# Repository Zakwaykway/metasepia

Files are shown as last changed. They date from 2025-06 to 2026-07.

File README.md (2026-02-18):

# Metasepia

An ergogenerated hummingbird-esque keyboard, inspired by jcmkk3's rufous, modified to my taste.

v2 is in development.

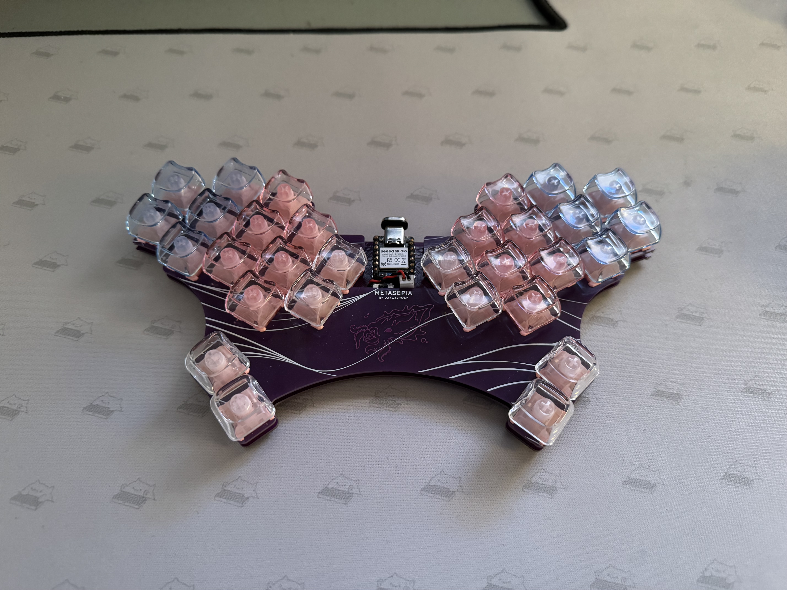
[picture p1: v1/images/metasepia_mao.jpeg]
mao


## Notable changes
  - Aggressive stagger (especially on index),
  - Wider thumbs,
  - Wireless compatibility,
  - Hotswappable,
  - And a breakable bottom pinky key (bound to top pinky's assignment in v1).

The pcb in v1/production is tested; fully functional with both xiao rp2040 & xiao nrf52840.

ZMK module (wired + wireless firmware) can be found at [zmk-keyboard-metasepia](https://github.com/zakwaykway/zmk-keyboard-metasepia).

front | back
-|-
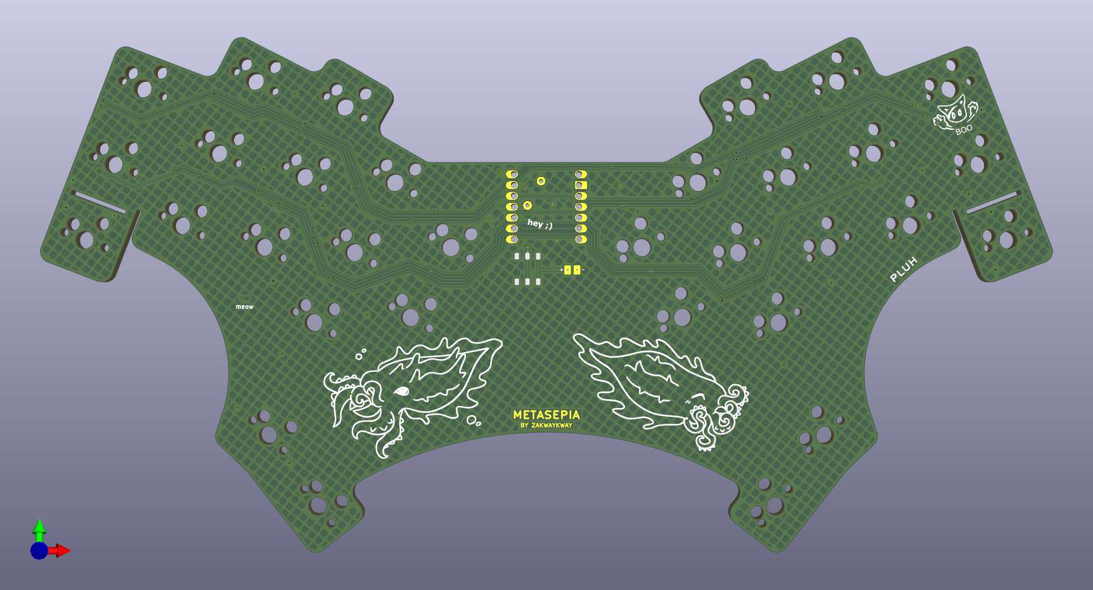
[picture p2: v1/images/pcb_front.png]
front
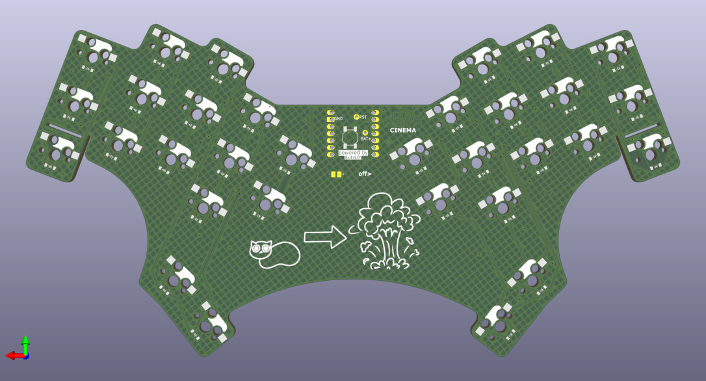
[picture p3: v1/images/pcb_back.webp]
back
 | 

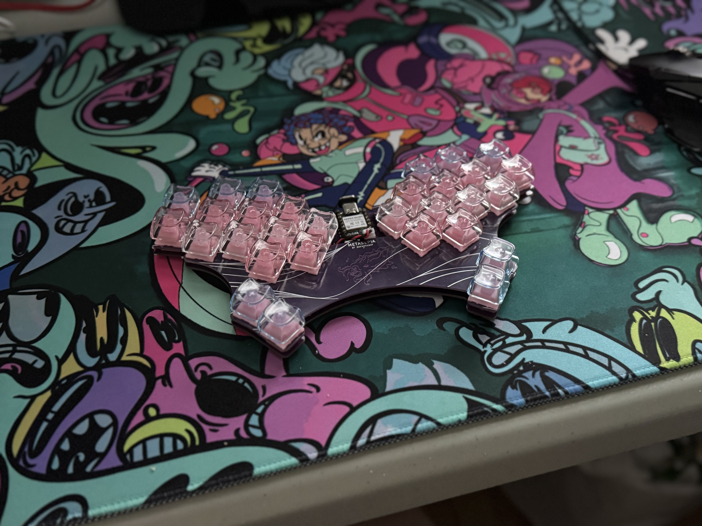
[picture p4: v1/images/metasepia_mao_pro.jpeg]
pro


## Assembly
### Components
- BOM.md
- If wireless isn't needed: BAT+ pogo, power slider, and battery aren't needed. Reset pogo & button are also optional, as there are other ways to trigger a reset.

### Build guide
0. **Optional:** remove bottom pinky key by cutting its traces, scoring the pcb at the tabs, and snapping off.
1. On **back** face: Tin **ONE** pad of each component.
2. Insert all hotswap sockets, and reflow tinned pads.
3. For diodes, I place and reflow one at a time, because they are a lot smaller & tend to jump around. 
4. Then, solder diodes' and sockets' 2nd (untinned) pads.
5. Solder reset button. 
6. On **front** face: solder slider switch, then MCU sockets.
7. Solder pogos. If male pins aren't soldered to the mcu yet, do that BEFORE adding pogos—doing it after is very tedious and annoying.
8. If careful, it IS POSSIBLE to solder a female JST-PH 2-pin connector. Its legs should be pointed **away** from the MCU (south). It is important that it be placed as close to the MCU as possible, or the plate won't fit over it.
9. **Enjoy your new keyboard!** Send me pics, suggestions, or comments @zakwaykway on discord \:))

## Thanks:
Making metasepia was an intensive learning experience, and a huge pride. 
Thanks to mrzealot for ergogen, ceoloide for their fork of ergogen, flatfootfox for their guide to ergogen; 
To the fingerpunch and 40% keyboard servers for questions and inspiration; 
To jcmkk3 for rufous' ergogen config; 
To ZMK for being an amazing keyboard firmware; 
To my friends, for making the art that's on the board;
And to all who have open-sourced their work, whether pcbs, footprints, or firmware--this wouldn't be possible without you.

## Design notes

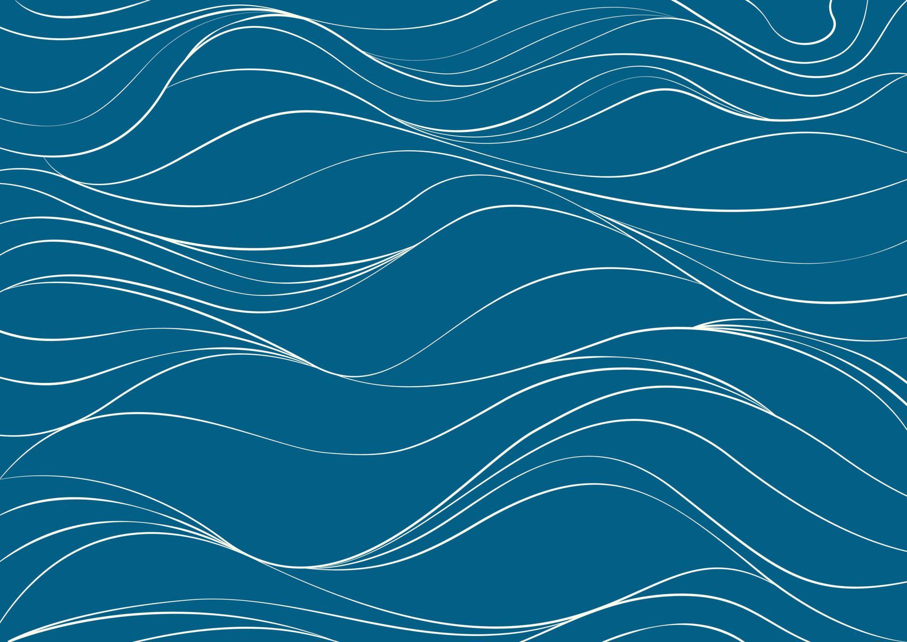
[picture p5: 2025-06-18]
art/abstract-texture-background-template-of-water-sea-aqua-ocean-river-or-mountain-doodle-wavy-line-curve-linear-wave-free-form-repeat-pattern-stripe-ripple-flat-illustration-design-vector-1491954462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

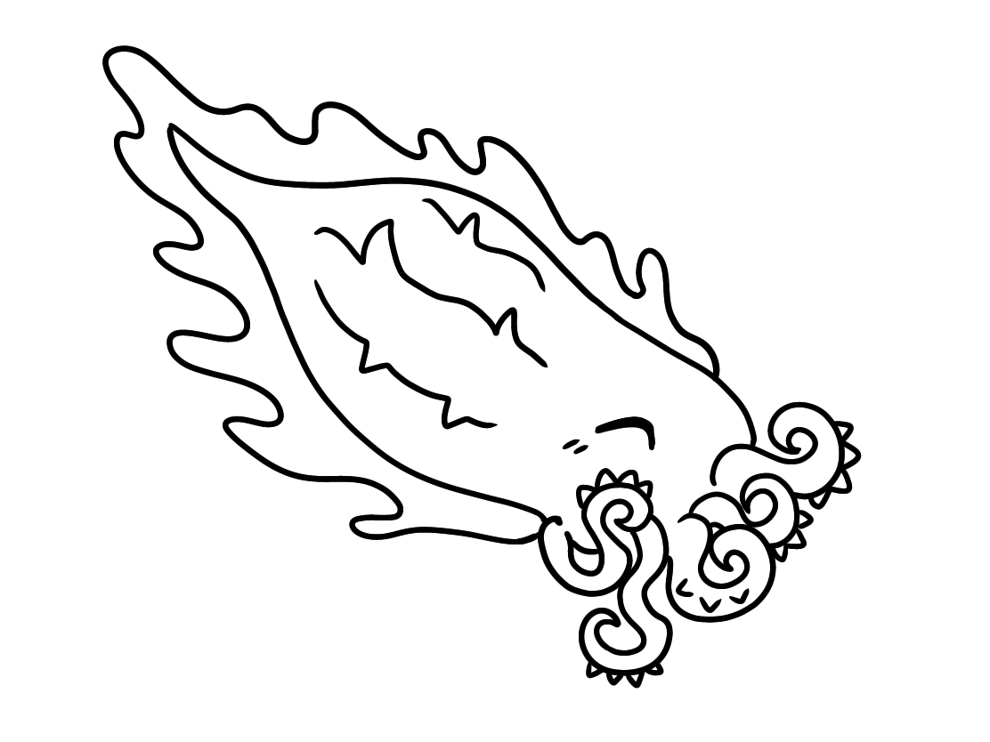
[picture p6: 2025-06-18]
art/metasepia_cute.png

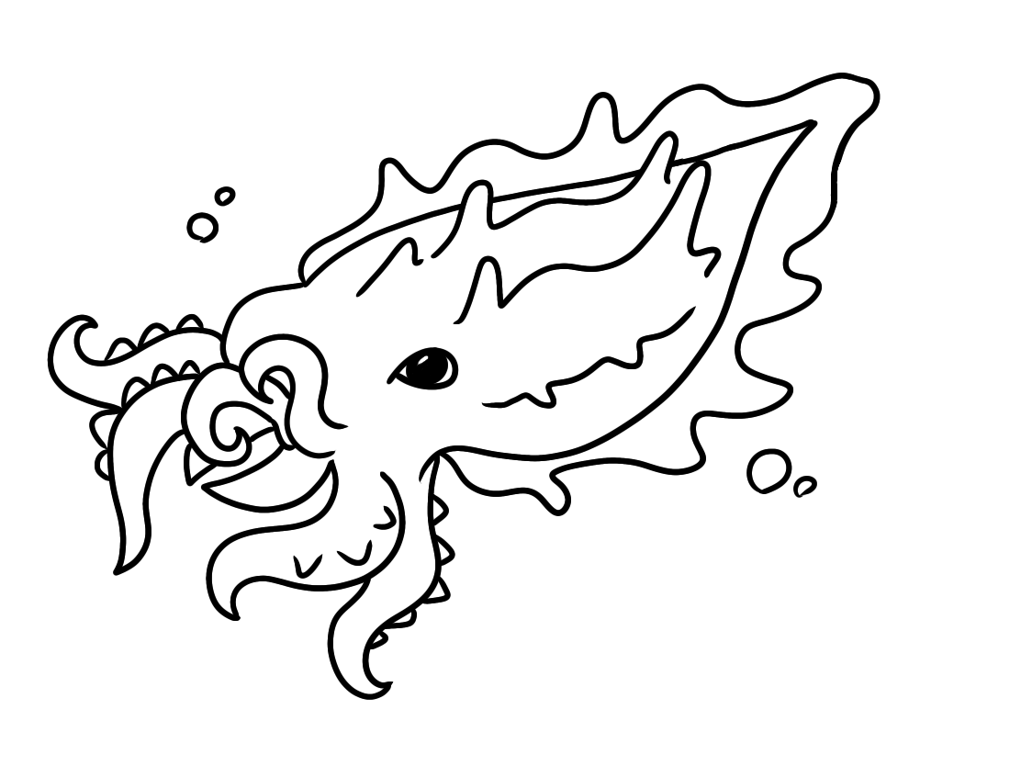
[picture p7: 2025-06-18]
art/metasepia_real.png

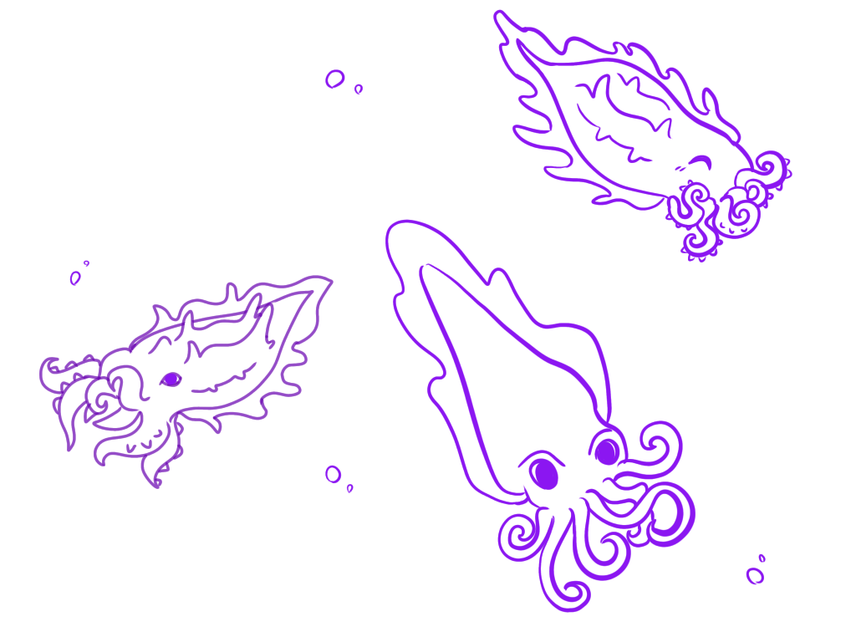
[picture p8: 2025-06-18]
art/metasepias.s.png

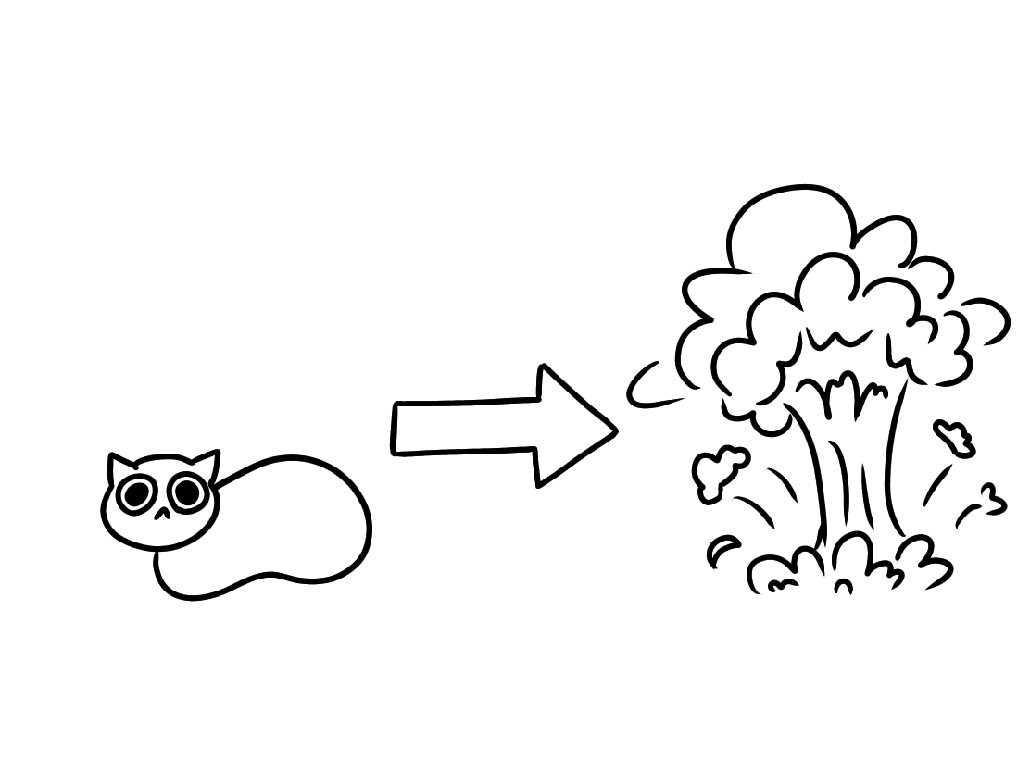
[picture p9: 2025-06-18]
art/cee.png

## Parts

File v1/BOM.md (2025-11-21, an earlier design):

| item | amount | price | notes |
|---|---|---|---|
| xiao BLE nRF54840 | 1 | 15$ | bluetooth & wired, zmk only |
| OR | | | |
| xiao rp2040 | 1 | 5$ | wired only, zmk & qmk |
| IN4148 SOD123 diodes | 30-32  | 2$ for 100 | |
| Kailh MX hotswap sockets | 30-32  | 10$ for 110 | |
| (OPTIONAL, wireless) MSS22D18 SMT slider switch | 1 | 2$ for 20 | on/off between bat & mcu |
| (OPTIONAL) ALPS skqg tactile switch | 1 | 2$ for 20 | need pogos if using headers |
| (OPTIONAL) 2.54mm pitch pin sockets | 14 | 3$ for 40 | to hotswap mcu |
| (OPTIONAL) RGBW headers, (cut in half) | 14 cut | 3$ for 10 rows>40 pins>80 halves| to hotswap mcu |
| (OPTIONAL) 4mm pogos | 2 | 5$ for 5 	| for rst & bat, if using headers |
| any battery with leads | 1 | varies | for wireless |
| 2P JST PH (2.0mm) female SMD connector			 | 1 | 2$ for 100 					| for wireless  				  |
| convenient: magnetic USBC adapter for reflashing | 1 | 4$ for plug & cable adapter | |
PCB + plate were 30$ + shipping

> soldering supplies
	- iron
	- stand for iron
	- pump, wick
	- flux
	- brass sponge
	- lead

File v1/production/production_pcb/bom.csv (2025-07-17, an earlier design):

Designator | Footprint | Quantity | Value | LCSC Part #
B1 | SW_TACT_ALPS_SKQGABE010 | 1
BT1 | BatteryPadsReversible | 1 | Battery_Cell
D1, D10, D11, D12, D13, D14, D15, D16, D17, D18, D19, D2, D20, D21, D22, D23, D24, D25, D26, D27, D28, D29, D3, D30, D31, D32, D4, D5, D6, D7, D8, D9 | diode_tht_sod123 | 32
MCU1 | xiao-pogo | 1 | xiao-ble
S1, S10, S11, S12, S13, S14, S15, S16, S17, S18, S19, S2, S20, S21, S22, S23, S24, S25, S26, S27, S28, S29, S3, S30, S31, S32, S4, S5, S6, S7, S8, S9 | switch_mx | 32

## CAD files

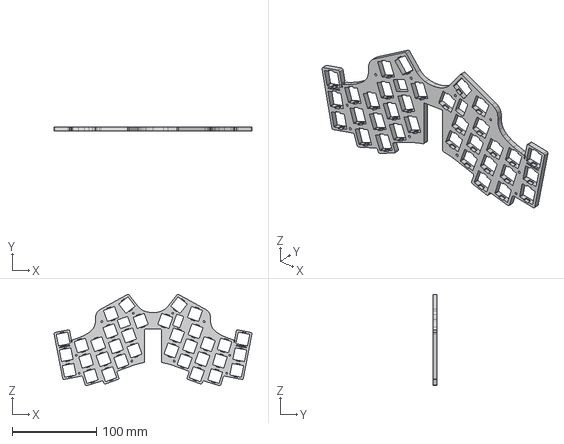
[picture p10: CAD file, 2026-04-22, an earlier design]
v2/production/production_plate/METASEPIA2MXTHICC.stp
235.6 x 4.75 x 108.8 mm

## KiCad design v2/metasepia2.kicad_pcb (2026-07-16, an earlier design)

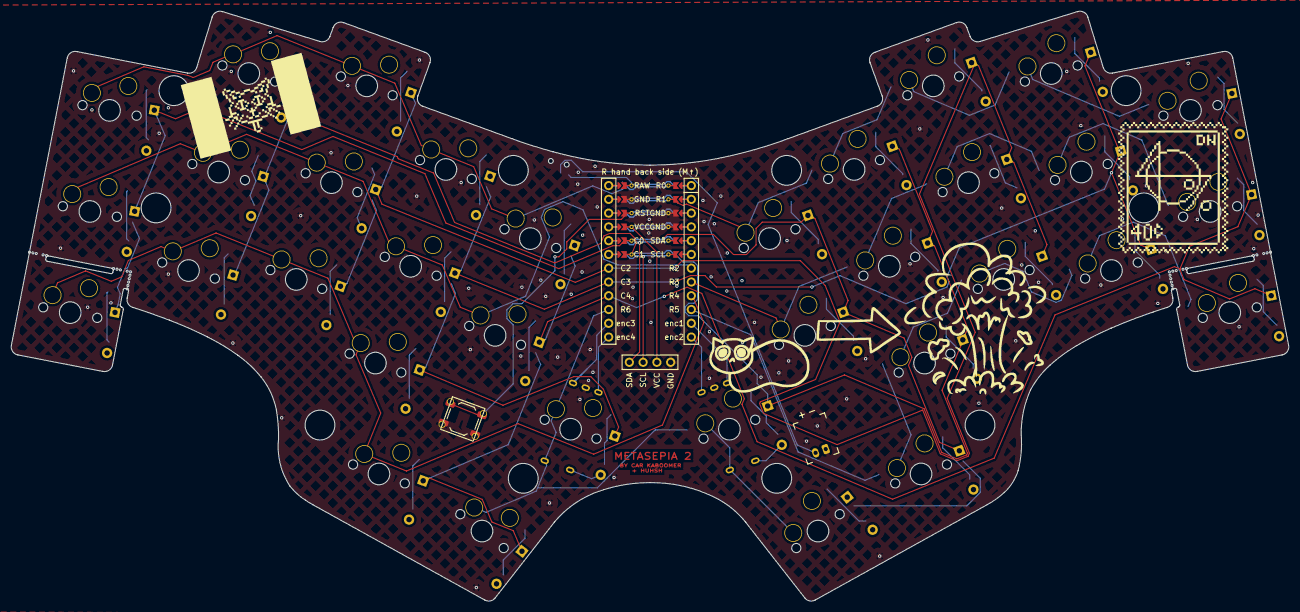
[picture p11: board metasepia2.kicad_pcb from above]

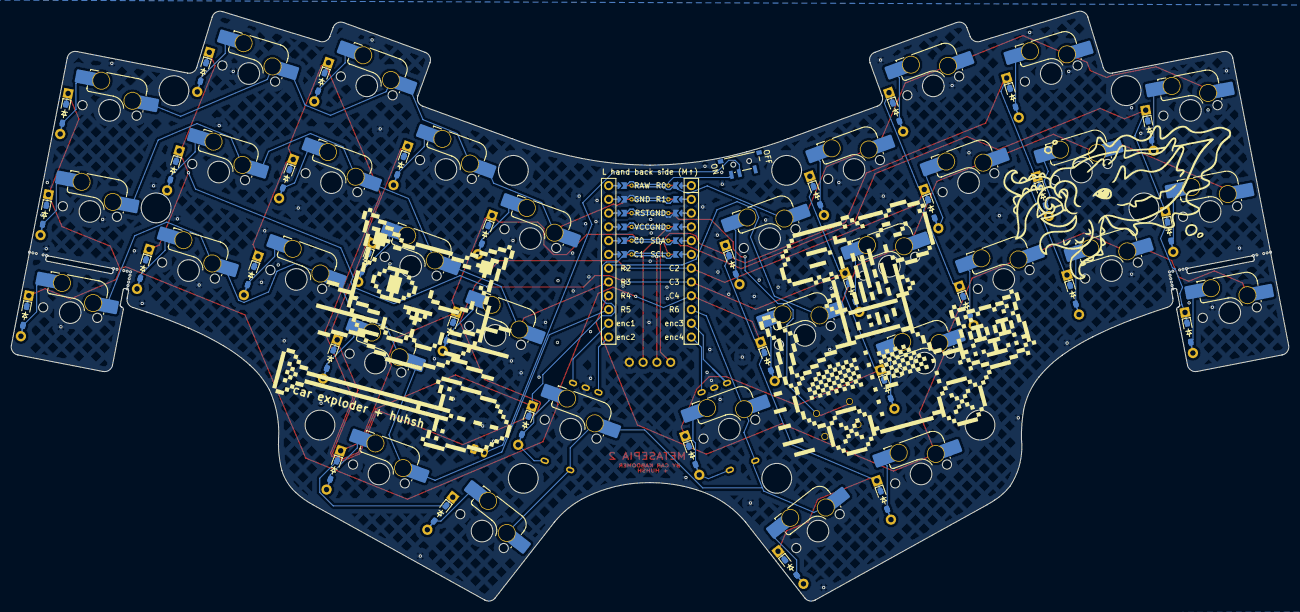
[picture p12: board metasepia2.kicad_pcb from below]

Board: 2 copper layers, 235.6 x 108.8 mm, 116 parts (35 on the bottom side), 57 nets.

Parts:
B1: button-alps-skqg
DISP1: display_ssd1306
JST1: battery_connector_jst_ph_2
MCU1: mcu_nice_nano
MH1, MH2, MH3, MH5, MH6, MH7, MH8, MH9, MH11, MH12, MH13, MH14, MH16, MH17, MH18, MH19, MH20, MH21, MH23, MH24, MH25, MH26, MH27, MH28, MH29, MH30, MH31, MH32, MH33, MH34, MH35, MH36, MH37, MH38, MH39, MH40, MH41, MH42, MH43, MH44: mounting_hole_npth
PWR1: power_switch_smd_side
RE1, RE2: rotary_encoder_ec11_ec12
XX1, XX2, XX3, XX4, XX5, XX6, XX7, XX8, XX9, XX10, XX11, XX12, XX13, XX14, XX15, XX16, XX17, XX18, XX19, XX20, XX21, XX22, XX23, XX24, XX25, XX26, XX27, XX28, XX29, XX30, XX31, XX32, XX33, XX34: hs-mx
XX35, XX36, XX37, XX38, XX39, XX40, XX41, XX42, XX43, XX44, XX45, XX46, XX47, XX48, XX49, XX50, XX51, XX52, XX53, XX54, XX55, XX56, XX57, XX58, XX59, XX60, XX61, XX62, XX63, XX64, XX65, XX66, XX67, XX68: diode_tht
XX69: button-6x6

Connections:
C0: MCU1.120, XX35.2, XX36.2, XX37.2, XX61.2, XX62.2, XX65.2, XX66.2
C1: MCU1.119, XX38.2, XX39.2, XX40.2, XX58.2, XX59.2, XX60.2, XX68.2
C2: MCU1.18, XX41.2, XX42.2, XX43.2, XX55.2, XX56.2, XX57.2
C3: MCU1.17, XX44.2, XX45.2, XX46.2, XX52.2, XX53.2, XX54.2, XX67.2
C4: MCU1.16, XX47.2, XX48.2, XX49.2, XX50.2, XX51.2, XX63.2, XX64.2
GND: B1.2, DISP1.4, JST1.1, MCU1.103, MCU1.104, MCU1.123, RE1.B, RE2.B, XX69.2
R0: MCU1.101, XX3.1, XX6.1, XX9.1, XX12.1, XX14.1
R1: MCU1.102, XX17.1, XX20.1, XX23.1, XX26.1, XX28.1
R2: MCU1.7, XX2.1, XX5.1, XX8.1, XX11.1, XX13.1
R3: MCU1.8, XX16.1, XX19.1, XX22.1, XX25.1, XX27.1
R4: MCU1.9, XX1.1, XX4.1, XX7.1, XX10.1, XX29.1
R5: MCU1.10, XX15.1, XX18.1, XX21.1, XX24.1, XX31.1
R6: MCU1.15, RE1.S2, RE2.S2, XX30.1, XX32.1, XX33.1, XX34.1
RAW: MCU1.124, PWR1.3
RST: B1.1, MCU1.122, XX69.1
SCL: DISP1.2, MCU1.106
SDA: DISP1.1, MCU1.105
VCC: DISP1.3, MCU1.121
battery: JST1.2, PWR1.2
default_default: RE1.S1, XX33.2, XX67.1
enc1: MCU1.14, RE1.A
enc2: MCU1.13, RE1.C
enc3: MCU1.12, RE2.A
enc4: MCU1.11, RE2.C
index_bottom: XX10.2, XX44.1
index_home: XX11.2, XX45.1
index_top: XX12.2, XX46.1
inner_home: XX13.2, XX47.1
inner_top: XX14.2, XX48.1
middle_bottom: XX7.2, XX41.1
middle_home: XX8.2, XX42.1
middle_top: XX9.2, XX43.1
mirror_default_default: RE2.S1, XX34.2, XX68.1
mirror_index_bottom: XX24.2, XX58.1
mirror_index_home: XX25.2, XX59.1
mirror_index_top: XX26.2, XX60.1
mirror_inner_home: XX27.2, XX61.1
mirror_inner_top: XX28.2, XX62.1
mirror_middle_bottom: XX21.2, XX55.1
mirror_middle_home: XX22.2, XX56.1
mirror_middle_top: XX23.2, XX57.1
mirror_pinky_bottom: XX15.2, XX49.1
mirror_pinky_home: XX16.2, XX50.1
mirror_pinky_top: XX17.2, XX51.1
mirror_reachy_default: XX32.2, XX66.1
mirror_ring_bottom: XX18.2, XX52.1
mirror_ring_home: XX19.2, XX53.1
mirror_ring_top: XX20.2, XX54.1
mirror_tucky_default: XX31.2, XX65.1
pinky_bottom: XX1.2, XX35.1
pinky_home: XX2.2, XX36.1
pinky_top: XX3.2, XX37.1
reachy_default: XX30.2, XX64.1
ring_bottom: XX4.2, XX38.1
ring_home: XX5.2, XX39.1
ring_top: XX6.2, XX40.1
tucky_default: XX29.2, XX63.1

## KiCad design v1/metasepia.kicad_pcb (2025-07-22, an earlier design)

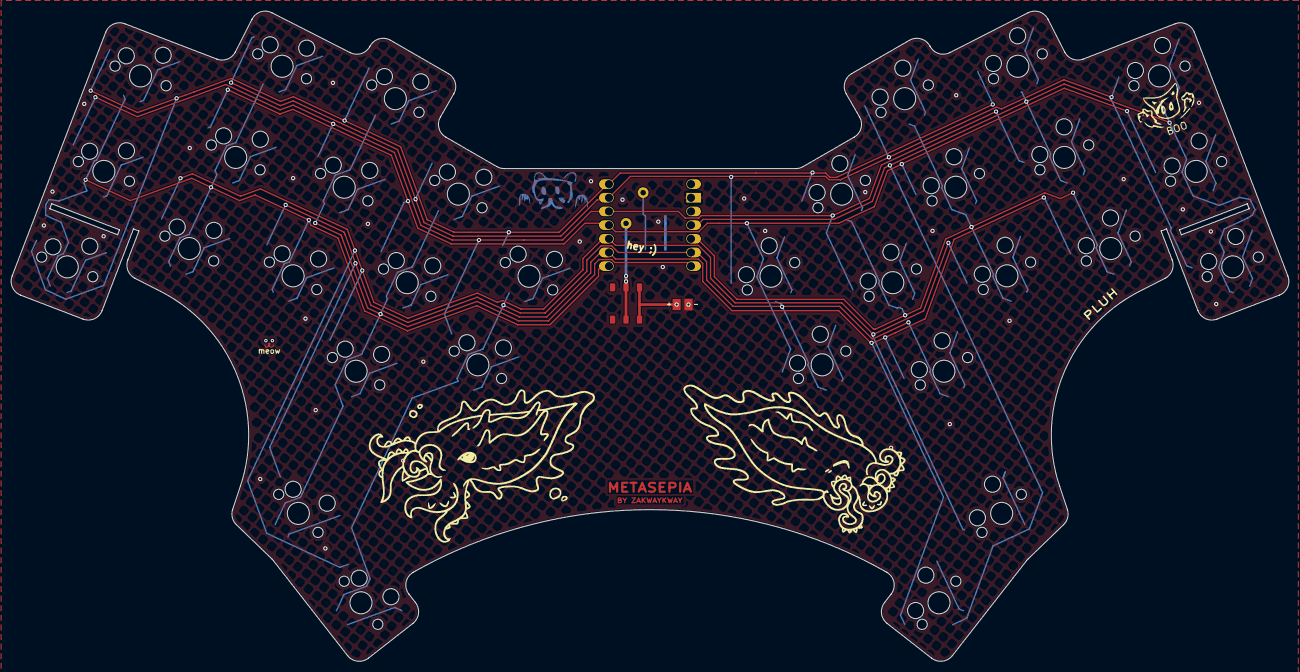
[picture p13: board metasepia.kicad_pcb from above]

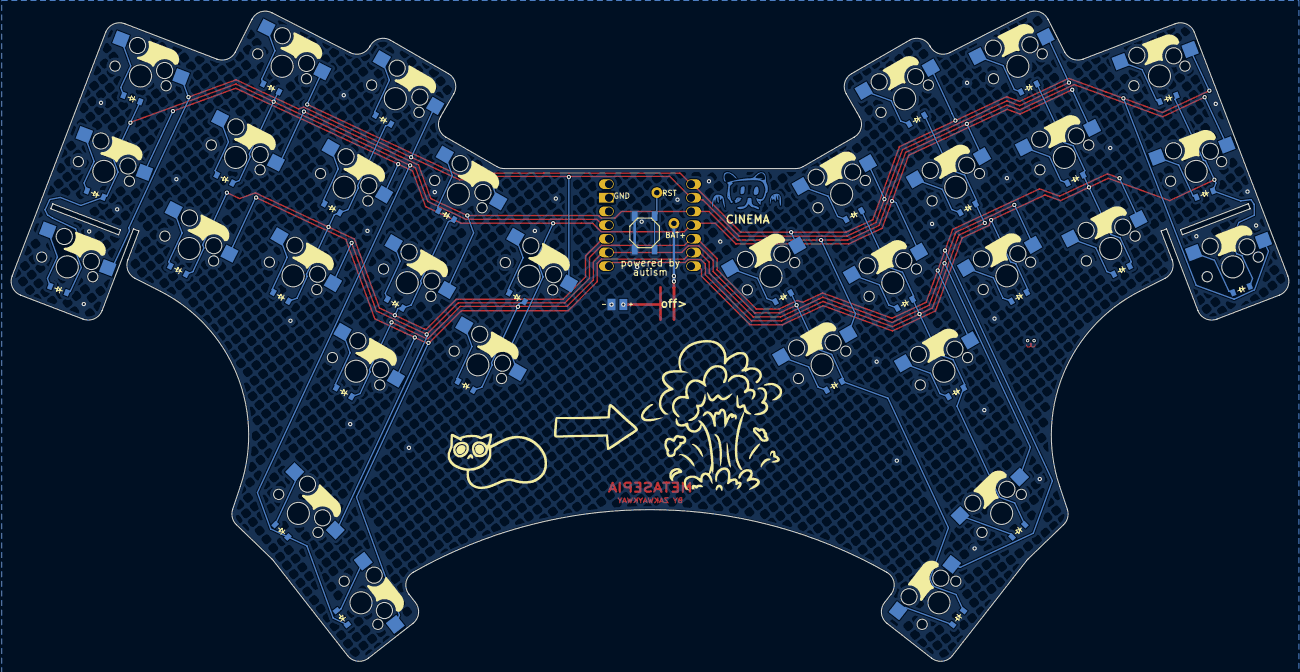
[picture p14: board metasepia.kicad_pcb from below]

Board: 2 copper layers, 237.4 x 120.8 mm, 67 parts (64 on the bottom side), 45 nets.

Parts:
B1: SW_TACT_ALPS_SKQGABE010
BT1: Battery_Cell; BatteryPadsReversible
D1, D2, D3, D4, D5, D6, D7, D8, D9, D10, D11, D12, D13, D14, D15, D16, D17, D18, D19, D20, D21, D22, D23, D24, D25, D26, D27, D28, D29, D30, D31, D32: diode_tht_sod123
MCU1: xiao-ble; xiao-pogo
S1, S2, S3, S4, S5, S6, S7, S8, S9, S10, S11, S12, S13, S14, S15, S16, S17, S18, S19, S20, S21, S22, S23, S24, S25, S26, S27, S28, S29, S30, S31, S32: switch_mx

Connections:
GND: B1.2, BT1.2, MCU1.13
P0: MCU1.1, S1.1, S3.1, S9.1, S14.1, S20.1, S26.1
P1: MCU1.2, S6.1, S12.1, S15.1, S17.1, S23.1, S28.1
P2: MCU1.3, S2.1, S8.1, S13.1, S19.1, S25.1
P3: MCU1.4, S5.1, S11.1, S16.1, S22.1, S27.1
P4: MCU1.5, S4.1, S10.1, S21.1, S30.1, S31.1
P5: MCU1.6, S7.1, S18.1, S24.1, S29.1, S32.1
P6: D1.1, D2.1, D3.1, D4.1, D5.1, D6.1, D7.1, MCU1.7
P7: D8.1, D9.1, D10.1, D11.1, D12.1, D29.1, MCU1.8
P8: D13.1, D14.1, D24.1, D27.1, D28.1, D30.1, MCU1.9
P9: D18.1, D21.1, D22.1, D23.1, D25.1, D26.1, MCU1.10
P10: D15.1, D16.1, D17.1, D19.1, D20.1, D31.1, D32.1, MCU1.11
RST: B1.1, MCU1.18
index_bottom: D10.2, S10.2
index_home: D11.2, S11.2
index_top: D12.2, S12.2
inner_home: D13.2, S13.2
inner_top: D14.2, S14.2
middle_bottom: D7.2, S7.2
middle_home: D8.2, S8.2
middle_top: D9.2, S9.2
mirror_index_bottom: D24.2, S24.2
mirror_index_home: D25.2, S25.2
mirror_index_top: D26.2, S26.2
mirror_inner_home: D27.2, S27.2
mirror_inner_top: D28.2, S28.2
mirror_middle_bottom: D21.2, S21.2
mirror_middle_home: D22.2, S22.2
mirror_middle_top: D23.2, S23.2
mirror_pinky_bottom: D15.2, S15.2
mirror_pinky_home: D16.2, S16.2
mirror_pinky_top: D17.2, S17.2
mirror_reachy_default: D32.2, S32.2
mirror_ring_bottom: D18.2, S18.2
mirror_ring_home: D19.2, S19.2
mirror_ring_top: D20.2, S20.2
mirror_tucky_default: D31.2, S31.2
pinky_bottom: D1.2, S1.2
pinky_home: D2.2, S2.2
pinky_top: D3.2, S3.2
reachy_default: D30.2, S30.2
ring_bottom: D4.2, S4.2
ring_home: D5.2, S5.2
ring_top: D6.2, S6.2
tucky_default: D29.2, S29.2

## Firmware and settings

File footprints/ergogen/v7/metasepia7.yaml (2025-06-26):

meta:
  engine: 4.1.0
  name: metasepia_v6
  author: zakwaykway
  url: https://github.com/zakwaykway/metasepia
  
units:
  capx: u-1 # kc size
  capy: u-1
  kx: u # spacing
  ky: u
  adj: -0.45ky # offset for splayed cols
  xiao_x: 19 # xiao measurements
  xiao_y: 21
  $default_height: 0
  $default_width: 0
  switch: 16 # switch size
  b: 0.05kx # bind for edges

  spacing: xiao_x - 2.5
  angle: 31  # between halves
  curve: 55 + spacing
  curve_shift: 5
  center_block: 4kx # mid width
  mcu_y: 20 # mcu height from curve

  pinky_splay: 6
  ring_stagger: 0.6ky
  ring_splay: 3
  middle_stagger: 0.2ky
  middle_splay: 0
  index_stagger: -0.5ky
  inner_stagger: -0.4ky
  thumb_stagger: -0.2ky
  thumb_base_angle: -14
  thumb_splay: -12
  thumb_adj: 1
  thumb_shiftx: 0.7kx
  thumb_shifty: -1.35ky


points:
  zones.matrix: 
    anchor.shift: [90, -70]
    rotate: -angle + pinky_splay + ring_splay + middle_splay
    mirror:
      ref: matrix_inner_top
      shift: [0.5kx, 0.5kx]
      distance: spacing
    key:
      width: capx
      height: capy
      spread: kx
      padding: ky
      autobind: 0
    rows:
      bottom:
      home:
      top:
    columns.pinky:
      rows:
        bottom: 
          bind: [0.5ky, b, 0, b]
          row_net: P0
          column_net: P6
        home:
          bind: [0.5ky, 0.5kx, 0, b]
          row_net: P2
          column_net: P6
        top:
          bind: [0, 0.5kx, 0.5ky, b]
          row_net: P0
          column_net: P6
        bottom.mirror:
          row_net: P0
          column_net: P6
        home.mirror:
          row_net: P3
          column_net: P10
        top.mirror:
          row_net: P1
          column_net: P10
    columns.ring:
      key:
        stagger: ring_stagger
        splay: -pinky_splay
        origin: [0, adj]
      rows:
        bottom:
          bind: [0.5ky, 0, 0, 0.5kx]
          row_net: P4
          column_net: P6
        home:
          bind: [0.5ky, 0.5kx, 0.5ky, 0]
          row_net: P3
          column_net: P6
        top:
          bind: [0, 1kx, 0.5ky, b]
          row_net: P1
          column_net: P6
        bottom.mirror:
          row_net: P5
          column_net: P9
        home.mirror:
          row_net: P2
          column_net: P10
        top.mirror:
          row_net: P0
          column_net: P10
    columns.middle:
      key:
        stagger: middle_stagger
        splay: -ring_splay
        origin: [0, adj]
      rows:
        bottom:
          bind: [0.5ky, 0.5kx, 0, 0.5kx]
          row_net: P5
          column_net: P6
        home:
          bind: [0.5ky, 0.5kx, 0.5ky, 0.5kx]
          row_net: P2
          column_net: P7
        top:
          bind: [0, b, 0.5ky, b]
          row_net: P0
          column_net: P7
        bottom.mirror:
          row_net: P4
          column_net: P9
        home.mirror:
          row_net: P3
          column_net: P9
        top.mirror:
          row_net: P1
          column_net: P9
    columns.index:
      key:
        stagger: index_stagger
        splay: -middle_splay
      rows:
        bottom:
          bind: [0.5ky, 0.5kx, 0, b]
          row_net: P4
          column_net: P7
        home:
          row_net: P3
          column_net: P7
        top:
          bind: [0, 0, 0.5ky, 0.5kx]
          row_net: P1
          column_net: P7
        bottom.mirror:
          row_net: P5
          column_net: P8
        home.mirror:
          row_net: P2
          column_net: P9
        top.mirror:
          row_net: P0
          column_net: P9
    columns.inner:
      key.stagger: inner_stagger
      rows:
        bottom.skip: true
        home:
          bind: [0.5ky, 0, 0.25ky, 0.5kx]
          row_net: P2
          column_net: P8
        top:
          bind: [0, 0, 0.5ky, 0.5kx]
          row_net: P0
          column_net: P8
        home.mirror:
          row_net: P3
          column_net: P8
        top.mirror:
          row_net: P1
          column_net: P8

  zones.thumb: # thumbs
    anchor:
      ref: matrix_index_bottom
      shift: [thumb_shiftx, thumb_shifty]
    mirror.$extends: points.zones.matrix.mirror
    key.$extends: points.zones.matrix.key
    columns:
      tucky:
        key:
          splay: thumb_base_angle
          bind: [1.5ky, b, 0, b]
          row_net: P5
          column_net: P7
        key.mirror:
          row_net: P4
          column_net: P10
      reachy:
        key:
          origin: [0, adj + thumb_adj]
          splay: thumb_splay
          stagger: thumb_stagger
          bind: [0, b, 0, 1kx]
          row_net: P4
          column_net: P8
        key.mirror:
          row_net: P5
          column_net: P10
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

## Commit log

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2025-02-25 Update and rename rufous.yaml to rufous-based.yaml
    need to figure out how to configure the footprints in troch.pretty. Then everything will make sense.
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2025-02-26 Add project files
    [matesepia.kicad_pcb, matesepia.kicad_sch]
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2025-02-27 syncing to desktop app
    [freerouting.dsn, matesepia.kicad_pcb, temp-freerouting.dsn]
2025-02-28 solve kicad outline errors
2025-02-28 Refining pcb for compatibility
    - non-ceoloide-dependant mountinghole footprint, added to ergogen footprints
    -corrected bad outline for pcb
    renamed some folders to be more accurate
2025-02-28 correct matesepia to metasepia everywhere
    [matesepia.kicad_pcb]
2025-03-01 Define new footprints in kicad
    customized diode; customized hotswap socket; customized xiao footprints. Created "frequent.pretty" footprint library for custom fp's. Next steps: art and routing.
    [metasepia.kicad_pcb]
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2025-03-01 routed, badly. All diodes are fucked. Need redo.
2025-03-01 properly remaking traces from scratch. Half done.
    [metasepia_good.kicad_pcb]
2025-03-01 clearing up kicad files
    [freerouting.dsn, matesepia.kicad_sch, metasepia bad routes.kicad_pcb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]
2025-03-02 almost finish routing
    [metasepia_good.kicad_pcb]
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2025-03-05 create metasepia2, edit diode footprint
    [metasepia_good.kicad_pcb]
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2025-03-05 fully route metasepiav2
    [metasepia_v2.kicad_pcb]
2025-03-06 changes to pcb
    [metasepia_v2.kicad_pcb]
2025-03-06 update bom, ergogen; tweak pcb
    set j value in ergogen config to 0. Hotswap sockets don't need vertical padding.
    [metasepia_v2.kicad_pcb]
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2025-03-15 update mtsp3
    [metasepia_v2.kicad_pcb_bom.csv, metasepia_v2.kicad_pcb_positions.csv]
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2025-03-19 create metasepia v3 pcb
    no wiring, init
    [metasepia_v3.kicad_pcb]
2025-03-19 wire metasepia3, create slider footprint, update footprints
    [metasepia_v3.kicad_pcb]
2025-03-19 update bom, optimize kicad tree
    [metasepia_ergogen.kicad_pcb, metasepia_good.kicad_pcb, metasepia_v2.kicad_pcb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]
2025-03-20 create slider switch, battery pad, add to v3
    [metasepia_v3.kicad_pcb]
2025-03-28 create v4 ergogen
    [metasepia_v4.kicad_pcb]
2025-04-23 metasepia5 create
    [metasepia_v4.kicad_pcb]
2025-04-30 begin kicadding metasepia5
    [metasepia_switchplate.kicad_pcb, metasepia_v5.kicad_pcb]
2025-04-30 Delete kicad backups directories
    Delete kicad backups directories
    Delete kicad backups directories
    Delete kicad backups directories
    Delete kicad backups directories
    Delete kicad/v4/fp-info-cache
    Delete kicad/v3/fp-info-cache
2025-05-02 pogo footprint part 1, begin tracing
    [metasepia_v5.kicad_pcb]
2025-05-03 more metasepia5 routing, fix net issue in ergogen
    ergogen: must explicitly be `colrow` in pcb section
    [metasepia_v5.kicad_pcb]
2025-05-07 xiao-pogo fp and a bit of routing
    [metasepia_v5.kicad_pcb]
2025-05-08 almost finish routing v5
    [metasepia_v5.kicad_pcb]
2025-05-09 metasepia5 finish
    [metasepia_switchplate.kicad_pcb, metasepia_v5.kicad_pcb]
2025-05-09 bom, try plate
    plate gerber no workie, despite 3d render in kicad working
    [metasepia_switchplate.kicad_pcb]
2025-05-10 work on plate and change pcb accordingly
    [metasepia_switchplate.kicad_pcb, metasepia_v5.kicad_pcb]
2025-05-10 tweak pcb grounding
    [metasepia_v5.kicad_pcb]
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2025-05-20 change organization
    ergogen configs now in each version of metasepias
    [metasepia_ergogen.kicad_pcb, metasepia_good.kicad_pcb, metasepia_switchplate.kicad_pcb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]
2025-06-18 add existing files
    [metasepia_ergogen.kicad_pcb, metasepia_good.kicad_pcb, metasepia_switchplate.kicad_pcb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]
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2025-06-30 fix reset and gnd's positions
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2025-07-09 Update metasepia7.yaml and add KiCad project files
    FINAL metasepia7 layout. Only matrix changes from now on.
2025-07-09 finish routing, clear bugged circles
    all that's left is art
    [metasepia_switchplate.kicad_pcb, metasepia_v7.kicad_pcb]
2025-07-12 Add artwork and update footprints on PCB
    Added 'METASEPIA', 'LOGO', and 'tism' artwork footprints to the PCB. Adjusted the position of the SW_TACT_ALPS_SKQGABE010 footprint. Deleted the metasepia_switchplate.kicad_pro project file and updat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
    [metasepia_v7.kicad_pcb]
2025-07-17 finish v7 and switchplate, create production files
    [bom.csv, designators.csv, metasepia_switchplate.kicad_pcb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]
2025-07-18 Send to manu
    Finish metasepia7 and send to manufacture.
    Modified BatteryPadsReversible footprint to use rectangular SMD pads and adjusted silk text positions. Updated metasepia_v7.kicad_pcb with a defined stackup, new net, and minor polygon coordinate corrections. Production files reorganized and backup ZIPs removed.
    [bom.csv, designators.csv, metasepia_v7.kicad_pcb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]
2025-07-22 make breakoff tabs 2mm (were 1mm)
    [metasepia_v7.kicad_pcb]
2025-07-22 Update PCB and reorganize production files
    renamed prod pcb files from v7/production to v7/production_pcb, and it is revised
    [bom.csv, designators.csv, metasepia_v7.kicad_pcb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]
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2025-08-24 add many new footprints, delete many unused footprints, reorganize
2025-09-04 Remove temp.yaml from v6 directory
    Deleted the v6/temp.yaml file, which contained keyboard layout and PCB configuration data. This may be part of a cleanup or refactor to remove unused or obsolete configuration files.
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2025-10-11 improve combo switch, add it to ergogen with genteure's tool
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2025-11-15 post-production restructuring
    [bom.csv, designators.csv, metasepia.kicad_pcb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]
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2025-11-21 fix bom & images in readme
2025-11-21 relocate archive to sit in pcb/
    [metasepia_ergogen.kicad_pcb, metasepia_good.kicad_pcb, metasepia_switchplate.kicad_pcb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]
2025-12-02 add template: kicad8 to prevent bugged config
    [metasepia.yaml]
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2026-02-09 move all to v1, in preparation for v2
    [bom.csv, designators.csv, metasepia.kicad_pcb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]
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2026-04-22 finalize meta2 pcb
    [metasepia2.kicad_pcb]
2026-04-22 thicc plate for meta2 upload
    [METASEPIA2MXTHICC.stp]
2026-07-16 pcb was NOT final. very minor edit & reupload.
    not final version; silk is changed, pcb updated, prod files not updated i think
    [METASEPIA2MXTHICC.stp, metasepia2.kicad_pcb]
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
